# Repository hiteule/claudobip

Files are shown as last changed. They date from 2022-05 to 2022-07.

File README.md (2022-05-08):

# ClaudoBip

A bunch of electronic cards and software for office automation.

For more information, please read this [blog post].

List of cards :
* [HDMI-CEC] : Drive a TV via the HDMI-CEC protocol.

[blog post]: https://medium.com/blablacar/build-hardware-for-office-automation-34414b0d581a
[HDMI-CEC]:  https://github.com/hiteule/claudobip/tree/master/hdmi-cec

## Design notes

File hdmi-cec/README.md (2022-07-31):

# ClaudoBip HDMI-CEC

An electronic board designed to drive a TV via the HDMI-CEC protocol.
The instructions are transmitted by radio via a NRF24L01 module.

## PCB

The card must be powered with 5v via the min-usb connector.

The card was designed with [Eagle].
The additional [libraries] used are:
* ATMEGA328P-AU.lbr
* CONNECTORS.lbr
* NRF24L01.lbr
* regulator.lbr

## Software

The firmware turns on the TV when it receives the instruction "workday_start" via the radio and turn it off when it receive the instruction "workday_end".
After turning on the TV it switches to the HDMI2 input automatically. This value is hardcoded.

The HDMI-CEC management is handled by a custom library. You will find the information in the dedicated readme.

The firmware is compiled and uploaded with the Arduino IDE.

The additional libraries used are:
* NRFLite: Handle the radio management. You will found it in the official Arduino repo.
* CEC: Handle the CEC protocol. You will found it in the "libraries" directory.

[Eagle]:     https://www.autodesk.fr/products/eagle
[libraries]: https://github.com/hiteule/eagle-library

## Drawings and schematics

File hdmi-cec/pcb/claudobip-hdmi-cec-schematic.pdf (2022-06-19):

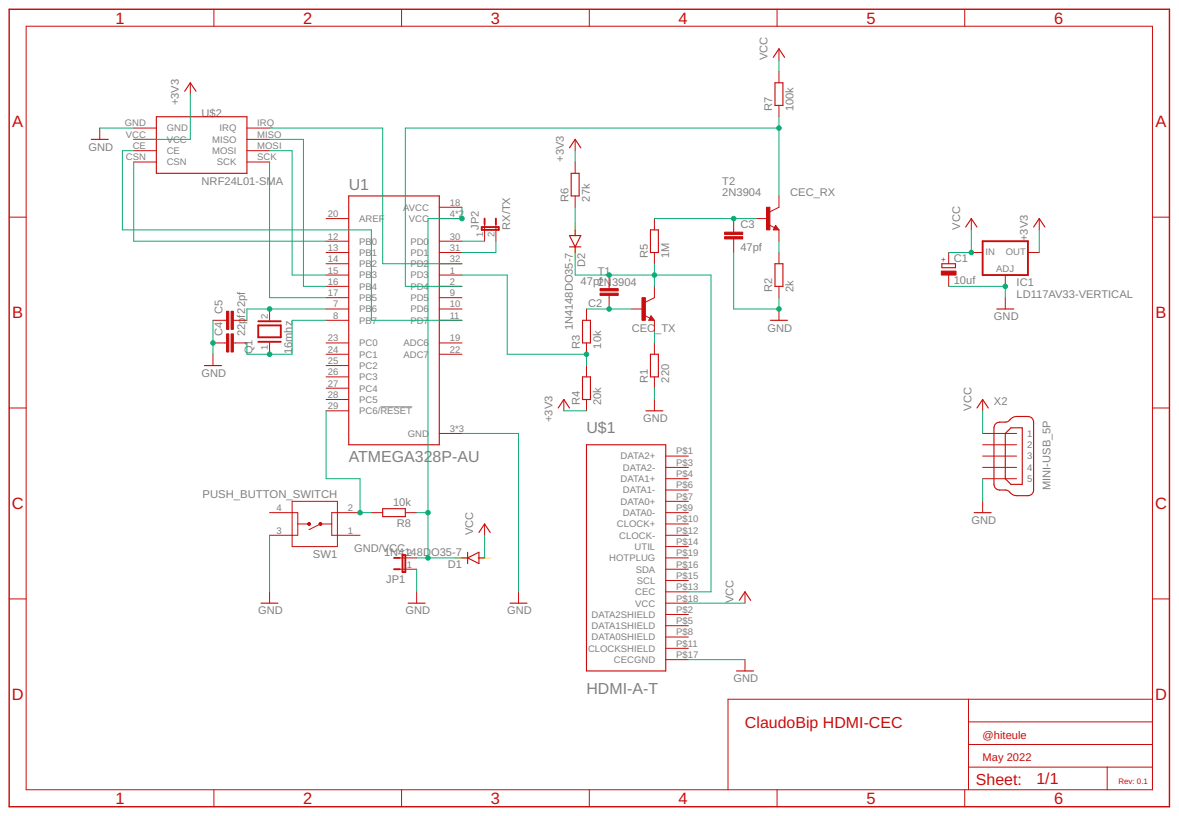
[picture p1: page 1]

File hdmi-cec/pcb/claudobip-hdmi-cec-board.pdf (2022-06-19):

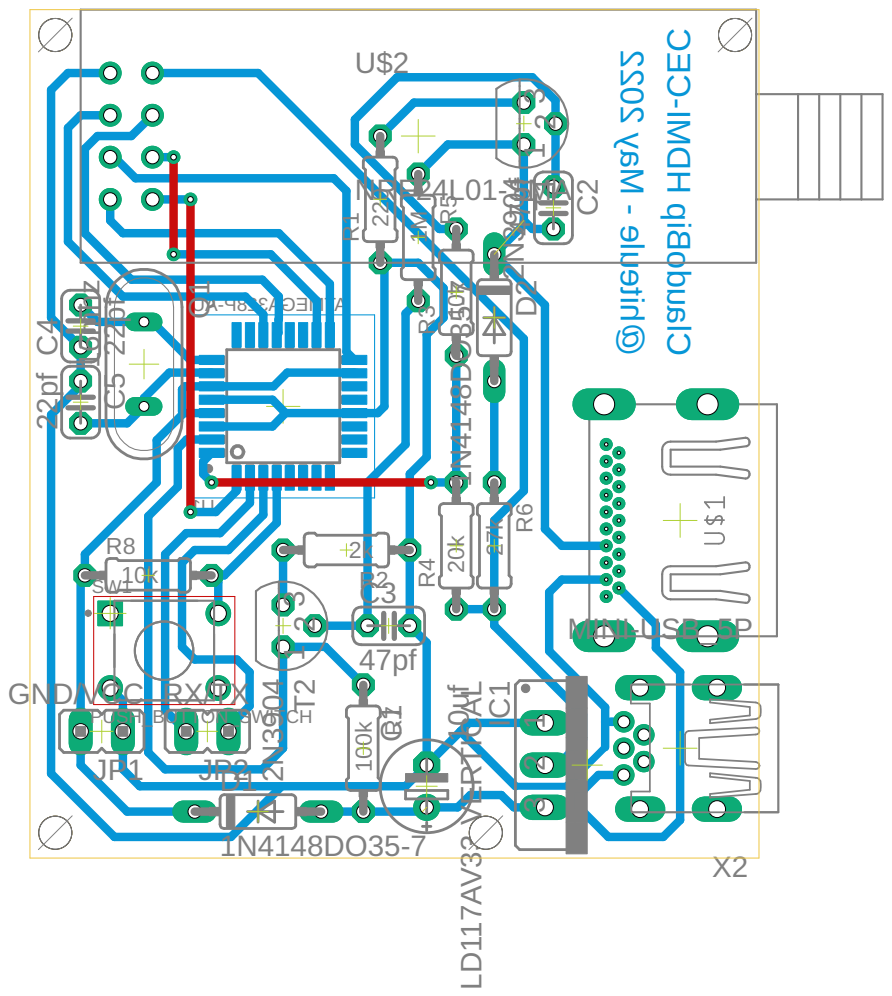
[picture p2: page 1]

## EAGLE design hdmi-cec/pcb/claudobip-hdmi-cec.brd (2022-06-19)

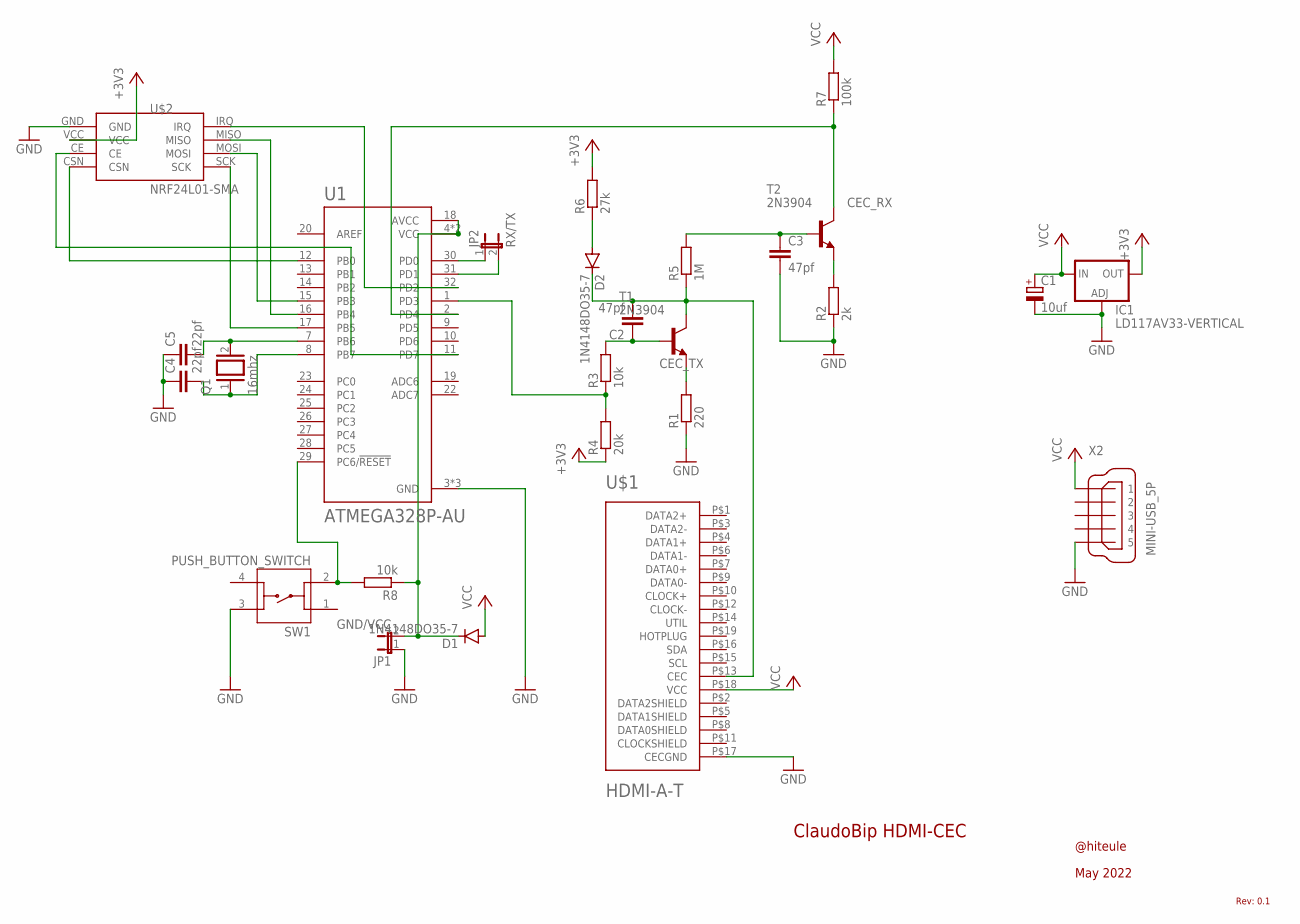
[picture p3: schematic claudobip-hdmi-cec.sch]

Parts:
C1: 10uf; E2,5-6E
C2, C3: 47pf; C025-024X044
C4, C5: 22pf; C025-024X044
D1, D2: 1N4148DO35-7; DO35-7
IC1: LD117AV33-VERTICAL; TO220S-VERTICAL
JP1: GND/VCC; JP1
JP2: RX/TX; JP1
Q1: 16mhz; QS
R1: 220; 0204/7
R2: 2k; 0204/7
R3, R8: 10k; 0204/7
R4: 20k; 0204/7
R5: 1M; 0204/7
R6: 27k; 0204/7
R7: 100k; 0204/7
SW1: PUSH_BUTTON_SWITCH
T1, T2: 2N3904; TO92
U1: ATMEGA328P-AU; QFP80P900X900X120-32N
U$1: HDMI-A-T; HDMI_A-T
U$2: NRF24L01-SMA
X2: MINI-USB_5P

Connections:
+3V3: IC1.2 (OUT), R4.1, R6.2, U$2.VCC
CEC_RX: R7.1, T2.1 (C), U1.2 (PD4)
CEC_TX: C2.1, R3.2, T1.2 (B)
GND: C1.-, C3.2, C4.1, C5.1, IC1.1 (ADJ), JP1.1, R1.1, R2.1, SW1.3, U1.3 (GND), U1.5 (GND), U1.21 (GND), U$1.P$17 (CECGND), U$2.GND, X2.5
unnamed: R1.2, T1.3 (E)
unnamed: C5.2, Q1.2, U1.7 (PB6)
unnamed: C4.2, Q1.1, U1.8 (PB7)
unnamed: R8.2, SW1.2, U1.29 (PC6/!RESET)
unnamed: D1.C, JP1.2, R8.1, U1.4 (VCC), U1.6 (VCC), U1.18 (AVCC)
unnamed: U1.16 (PB4), U$2.MISO
unnamed: U1.15 (PB3), U$2.MOSI
unnamed: U1.12 (PB0), U$2.CSN
unnamed: U1.11 (PD7), U$2.CE
unnamed: U1.32 (PD2), U$2.IRQ
unnamed: U1.17 (PB5), U$2.SCK
unnamed: JP2.1, U1.30 (PD0)
unnamed: JP2.2, U1.31 (PD1)
unnamed: R2.2, T2.3 (E)
unnamed: C3.1, R5.2, T2.2 (B)
unnamed: R3.1, R4.2, U1.1 (PD3)
unnamed: C2.2, D2.C, R5.1, T1.1 (C), U$1.P$13 (CEC)
unnamed: D2.A, R6.1
VCC: C1.+, D1.A, IC1.3 (IN), R7.2, U$1.P$18 (VCC), X2.1

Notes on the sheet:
Rev: 0.1
May 2022
@hiteule
ClaudoBip HDMI-CEC

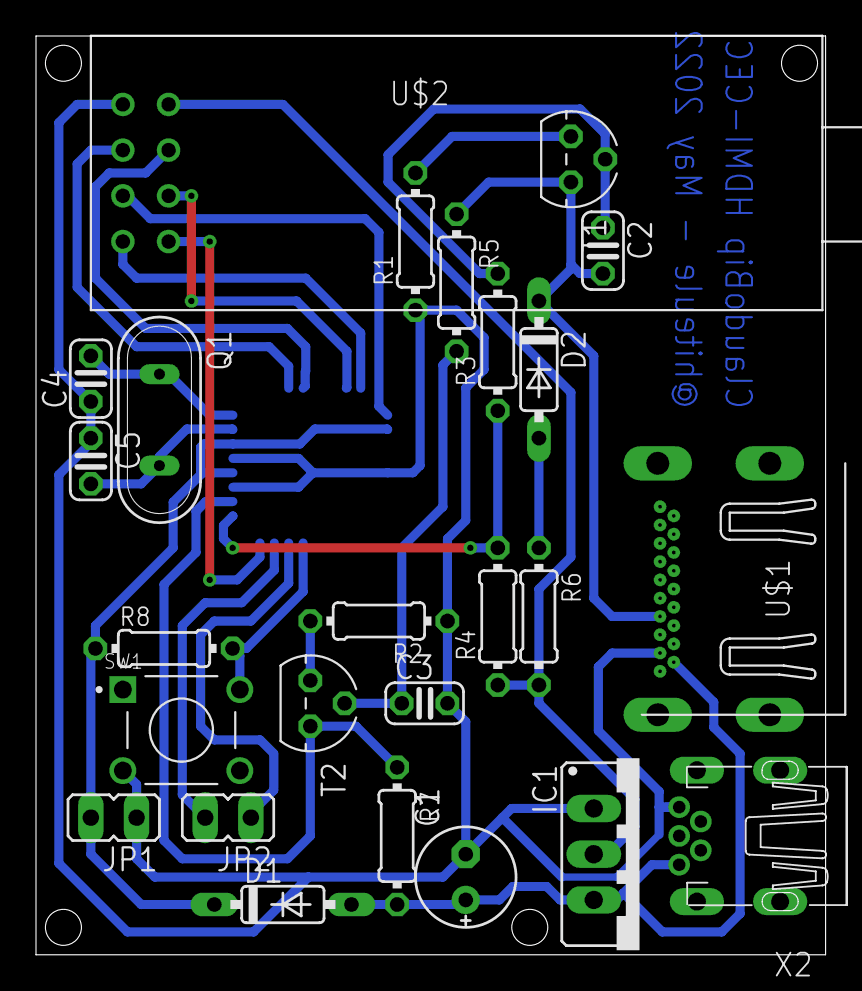
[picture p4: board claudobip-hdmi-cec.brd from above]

Board: 2 copper layers, 43.9 x 51.0 mm, 26 parts (1 on the bottom side), 23 nets.

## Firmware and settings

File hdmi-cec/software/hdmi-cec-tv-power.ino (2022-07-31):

#include <SPI.h>
#include <NRFLite.h>
#include "CEC_Device.h"

#define DEBUG 0
#define NRF_ADDR 1
#define NRF_CE_PIN 7
#define NRF_CSN_PIN 8

#define CEC_IN_LINE 4
#define CEC_OUT_LINE 3

#define report(X) do { report ## X (); } while (0)

#define phy1 ((_physicalAddress >> 8) & 0xFF)
#define phy2 ((_physicalAddress >> 0) & 0xFF)

class MyCEC: public CEC_Device {
  public:
    MyCEC(int physAddr): CEC_Device(physAddr, CEC_IN_LINE, CEC_OUT_LINE) { }
    
    void reportPhysAddr()    { unsigned char frame[4] = { 0x84, phy1, phy2, 0x04 };        TransmitFrame(0x0F, frame, sizeof(frame)); } // Report physical address
    void reportStreamState() { unsigned char frame[3] = { 0x82, phy1, phy2 };              TransmitFrame(0x0F, frame, sizeof(frame)); } // Report stream state (playing)
    void reportPowerState()  { unsigned char frame[2] = { 0x90, 0x00 };                    TransmitFrame(0x00, frame, sizeof(frame)); } // Report power state (on)
    void reportCECVersion()  { unsigned char frame[2] = { 0x9E, 0x04 };                    TransmitFrame(0x00, frame, sizeof(frame)); } // Report CEC version (v1.3a)
    void reportOSDName()     { unsigned char frame[7] = { 0x47, 'C','L','A','U','D','E' }; TransmitFrame(0x00, frame, sizeof(frame)); } // FIXME: name hardcoded
    void reportVendorID()    { unsigned char frame[4] = { 0x87, 0x00, 0xF1, 0x0E };        TransmitFrame(0x00, frame, sizeof(frame)); } // Report fake vendor ID
    
    void OnReceive(int source, int dest, unsigned char* buffer, int count) {
      if (count == 0) return;
      switch (buffer[0]) {        
        case 0x36:
          /* standby */
          break;

        case 0x83:
          report(PhysAddr);
          break;

        case 0x86:
          if (buffer[1] == phy1 && buffer[2] == phy2) {
            report(StreamState);
          }
          break;

        case 0x8F:
          report(PowerState);
          break;

        case 0x9F:
          report(CECVersion);
          break;

        case 0x46:
          report(OSDName);
          break;

        case 0x8C:
          report(VendorID);
          break;

        default:
          CEC_Device::OnReceive(source,dest,buffer,count);
          break;
      }
    }
};

MyCEC cecDevice(0x1000);

unsigned long lastImageViewOn = millis();
bool srcChanged = true;

NRFLite nrf;

struct RadioData
{
  char action[16];
  char value[16];
};

RadioData radioData;

void setup()
{
  if (DEBUG) {
    Serial.begin(9600);
  }
  delay(1000);

  nrf.init(NRF_ADDR, NRF_CE_PIN, NRF_CSN_PIN);

  cecDevice.Initialize(CEC_LogicalDevice::CDT_PLAYBACK_DEVICE);

  if (DEBUG) {
    Serial.println("Showtime !");
  }
}

void loop()
{
  uint8_t packetSize = nrf.hasData();

  if (sizeof(RadioData) == packetSize) {
    nrf.readData(&radioData);

    String action = String(radioData.action);
    String value = String(radioData.value);

    if (DEBUG) {
      Serial.print("Received <");
      Serial.print(action);
      Serial.print(":");
      Serial.print(value);
      Serial.println(">");
      delay(5000);
    }

    if (action.equals("workday_start")) {
      tvPower(true);
    } else if (action.equals("workday_end")) {
      tvPower(false);
    }
  }

  if (!srcChanged && (lastImageViewOn + 15000) < millis()) {
    changeSrc();
  }

  cecDevice.Run();
}

void tvPower(bool state)
{
  unsigned char buffer[2] = { 0x00, 0x00 };

  if (state) {
    if (DEBUG) {
      Serial.println("CEC: Image view on");
    }

    srcChanged = false;
    lastImageViewOn = millis();

    // Image view on
    buffer[0] = 0x04;
    cecDevice.TransmitFrame(0, buffer, 1);

    return;
  }

  if (DEBUG) {
    Serial.println("CEC: standby");
  }

  // Standby
  buffer[0] = 0x36;
  cecDevice.TransmitFrame(0, buffer, 1);
}

void changeSrc()
{
  srcChanged = true;

  // Active Source, HDMI 2
  unsigned char buffer[3] = { 0x82, 0x20, 0x00 };

  if (DEBUG) {
    Serial.println("CEC: Active source");
  }

  cecDevice.TransmitFrame(15, buffer, 3);
}

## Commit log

2022-05-08 [HDMI-CEC] Add pcb schematic & board
    [claudobip-hdmi-cec.brd, claudobip-hdmi-cec.sch]
2022-06-19 [HDMI-CEC] Use a vertical footprint for the LD117AV33 regulator
    [claudobip-hdmi-cec.brd, claudobip-hdmi-cec.sch]
